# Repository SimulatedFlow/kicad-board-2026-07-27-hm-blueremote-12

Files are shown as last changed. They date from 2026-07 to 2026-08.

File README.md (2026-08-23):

# 2026-07-27-hm-blueremote-12

<!-- SF-STORE-BLOCK:BEGIN -->
## 🛒 Source-available — see before you buy

This repository contains the **full design files** of a commercial hardware board. It is **source-available, not open source**: read it, evaluate it, then buy a license to use it. See **LICENSE.md (source-available, purchase required)**.

**Get it / Buy:**
- **Order on eBay** (this board, bare PCB): https://www.ebay.de/itm/398223886097
- Product page (specs, photos, price): https://simulatedflow.teufel-engineering.com/platinen/2026-07-27-hm-blueremote-12/
- eBay store — all our boards and PCB art: https://www.ebay.de/usr/simula-9
- Merch shop (dev & gaming): https://simulatedflow.myspreadshop.de
- Merch shop (Synthetica / EDM): https://synthetica.myspreadshop.de
- Direct / invoice (Simulated Flow UG): simulatedflow@gmail.com

### 📬 **Free Board Documentation & Firmware Pack**

Schematics, BOMs and example-firmware docs for our STM32 carrier boards. Get it by joining the newsletter — plus a heads-up when something new ships. Double opt-in, unsubscribe in one click, no address sharing.

👉 **[Get the free pack](https://simulatedflow.teufel-engineering.com/newsletter/hardware/?q=gh)**

_© 2026 Simulated Flow UG. All rights reserved._
<!-- SF-STORE-BLOCK:END -->

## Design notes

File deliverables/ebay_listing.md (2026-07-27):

# HM-BlueRemote-12 - Leerplatine fuer STM32 Bluepill (unbestueckt/teilbestueckt, Bausatz-Basis)

Ein ultrakompakter 12-Tasten-Handsender für das Homematic-Ökosystem auf Basis eines STM32 Bluepill und CC1101-Funkmoduls.

## Highlights
- THT + SMD (Verkauf unbestueckt/teilbestueckt; schwer loetbare SMD optional fab-bestueckt)
- Passt direkt auf die STM32 'Bluepill' (2x 20-Pin-Buchsenleiste, 22,86 mm Reihenabstand)
- Schraubklemmen am Platinenrand - Kabel sauber nach aussen
- 4x M3-Befestigungsbohrungen fuer gaengige Gehaeuse
- 4-lagig (durchgehende GND- + Versorgungs-Plane, stoerarm/EMV-freundlich)

**Passendes Gehaeuse:** Hammond 1553B (Ergonomisches Handgehäuse, ca. 117x79x24mm)

## Einsatzzweck
Es fehlen fertige, anpassbare Homematic-Handsender (AskSinPP) mit hoher Tastenanzahl, die ohne Kabelsalat in ein Standard-Handgehäuse passen.

## Bestueckung (ca. 19 Bauteile laut Stueckliste)
- C1: 100nF (x1)
- C2: 10uF (x1)
- J1: 2xAAA 3V0 (x1)
- LED1: STATUS (x1)
- R1: 330 (x1)
- SW1: BTN1 (x1)
- SW2: BTN2 (x1)
- SW3: BTN3 (x1)
- SW4: BTN4 (x1)
- SW5: BTN5 (x1)
- SW6: BTN6 (x1)
- SW7: BTN7 (x1)
- SW8: BTN8 (x1)
- SW9: BTN9 (x1)
- SW10: BTN10 (x1)
- SW11: BTN11 (x1)
- SW12: BTN12 (x1)
- U1: STM32F103C8T6 (x1)
- U2: CC1101 (x1)

## Lieferumfang
- 1x unbestueckte Leiterplatte (Fertigung auf Bestellung via PCBWay)
- Schaltplan als PDF + Bestueckungsliste (BOM als CSV) zum Download

**Preis:** 19 EUR (unbestueckte Leerplatine, zzgl. Versand)

Fertigung auf Bestellung - Lieferzeit nach PCBWay-Produktion. Versand als versicherter Warenversand.

## Anbieter / Impressum (gewerblicher Verkauf)
Simulated Flow UG (haftungsbeschränkt)
Zeller Straße 37 A, 77833 Ottersweier, Deutschland
Vertreten durch den Geschäftsführer: Simulated Flow
Registergericht: Amtsgericht Mannheim, HRB 758925
USt-IdNr.: DE463825106
E-Mail: simulatedflow@gmail.com
Web: https://simulatedflow.teufel-engineering.com

Gewerblicher Verkauf durch die Simulated Flow UG — es gelten das gesetzliche Widerrufsrecht (14 Tage) und die gesetzliche Gewährleistung.

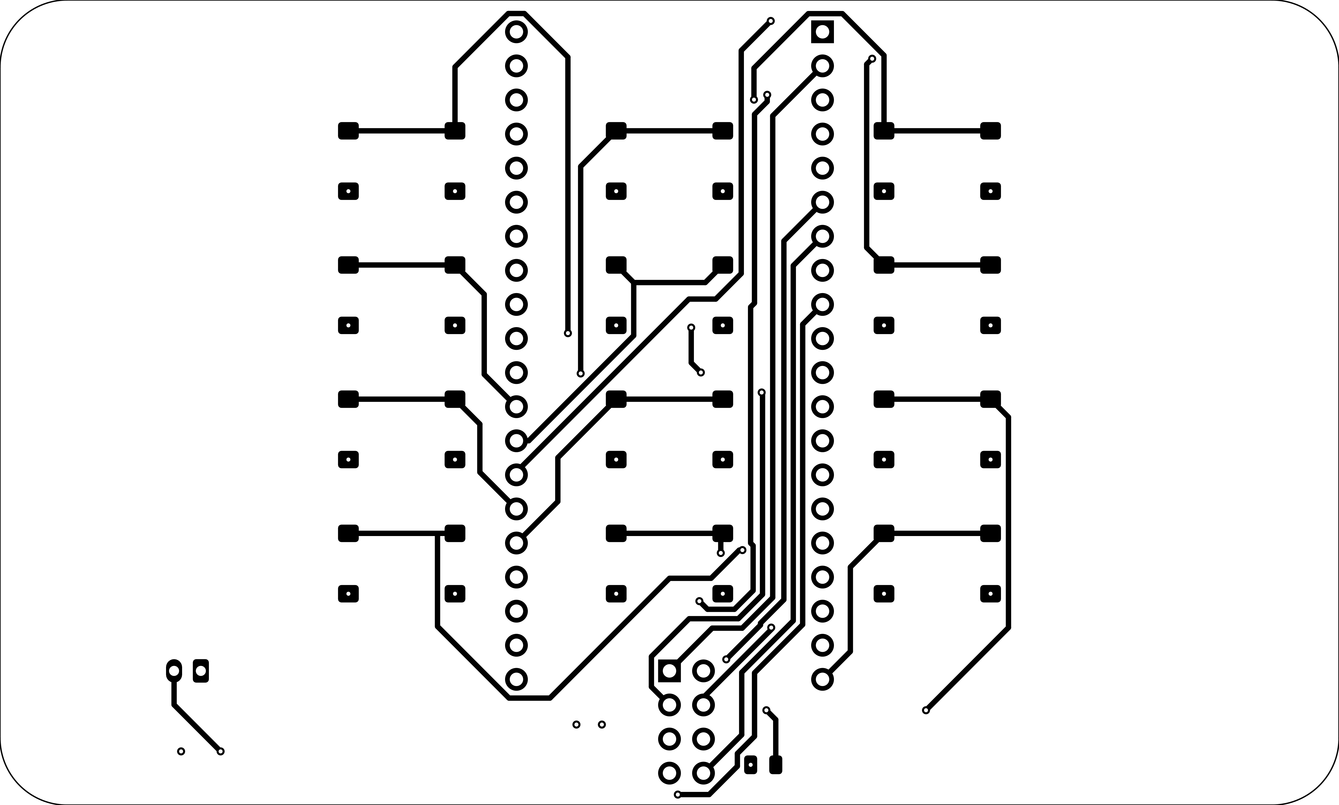
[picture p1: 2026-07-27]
HM-BlueRemote-12_2d_view.png

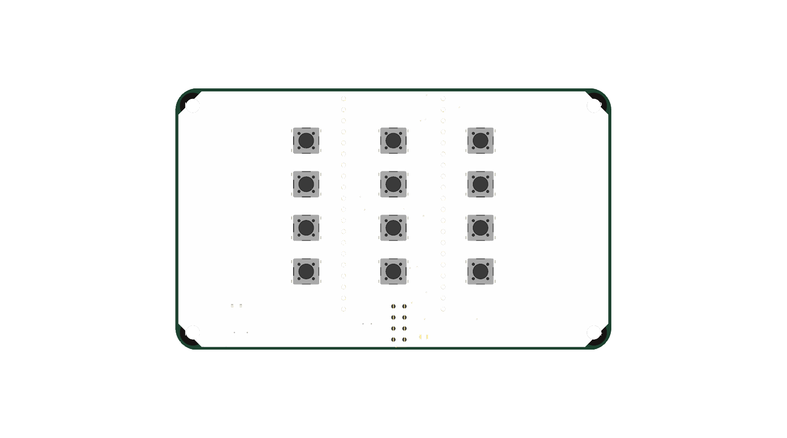
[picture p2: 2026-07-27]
deliverables/render_top.png

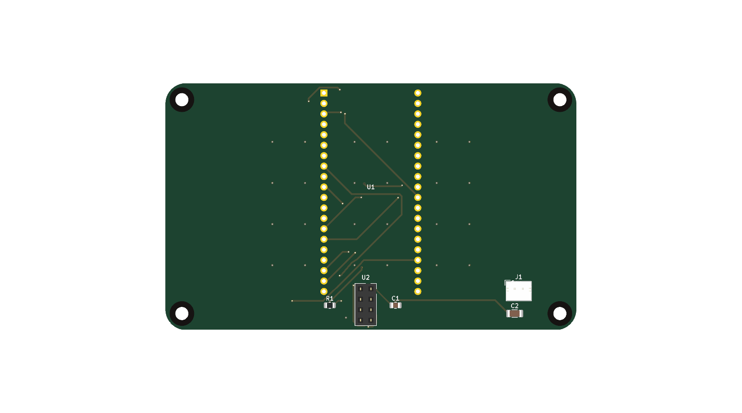
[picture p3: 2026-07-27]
deliverables/render_bottom.png

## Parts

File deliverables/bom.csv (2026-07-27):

Refs | Value | Footprint | Qty | DNP
C1 | 100nF | Capacitor_SMD:C_0805_2012Metric | 1
C2 | 10uF | Capacitor_SMD:C_1206_3216Metric | 1
J1 | 2xAAA 3V0 | Connector_JST:JST_PH_B2B-PH-K_1x02_P2.00mm_Vertical | 1
LED1 | STATUS | LED_SMD:LED_0805_2012Metric | 1
R1 | 330 | Resistor_SMD:R_0805_2012Metric | 1
SW1 | BTN1 | Button_Switch_SMD:SW_SPST_PTS645Sx43SMTR92 | 1
SW2 | BTN2 | Button_Switch_SMD:SW_SPST_PTS645Sx43SMTR92 | 1
SW3 | BTN3 | Button_Switch_SMD:SW_SPST_PTS645Sx43SMTR92 | 1
SW4 | BTN4 | Button_Switch_SMD:SW_SPST_PTS645Sx43SMTR92 | 1
SW5 | BTN5 | Button_Switch_SMD:SW_SPST_PTS645Sx43SMTR92 | 1
SW6 | BTN6 | Button_Switch_SMD:SW_SPST_PTS645Sx43SMTR92 | 1
SW7 | BTN7 | Button_Switch_SMD:SW_SPST_PTS645Sx43SMTR92 | 1
SW8 | BTN8 | Button_Switch_SMD:SW_SPST_PTS645Sx43SMTR92 | 1
SW9 | BTN9 | Button_Switch_SMD:SW_SPST_PTS645Sx43SMTR92 | 1
SW10 | BTN10 | Button_Switch_SMD:SW_SPST_PTS645Sx43SMTR92 | 1
SW11 | BTN11 | Button_Switch_SMD:SW_SPST_PTS645Sx43SMTR92 | 1
SW12 | BTN12 | Button_Switch_SMD:SW_SPST_PTS645Sx43SMTR92 | 1
U1 | STM32F103C8T6 | HM-BlueRemote-12:Bluepill_Socket_2x20 | 1
U2 | CC1101 | Connector_PinSocket_2.54mm:PinSocket_2x04_P2.54mm_Vertical | 1

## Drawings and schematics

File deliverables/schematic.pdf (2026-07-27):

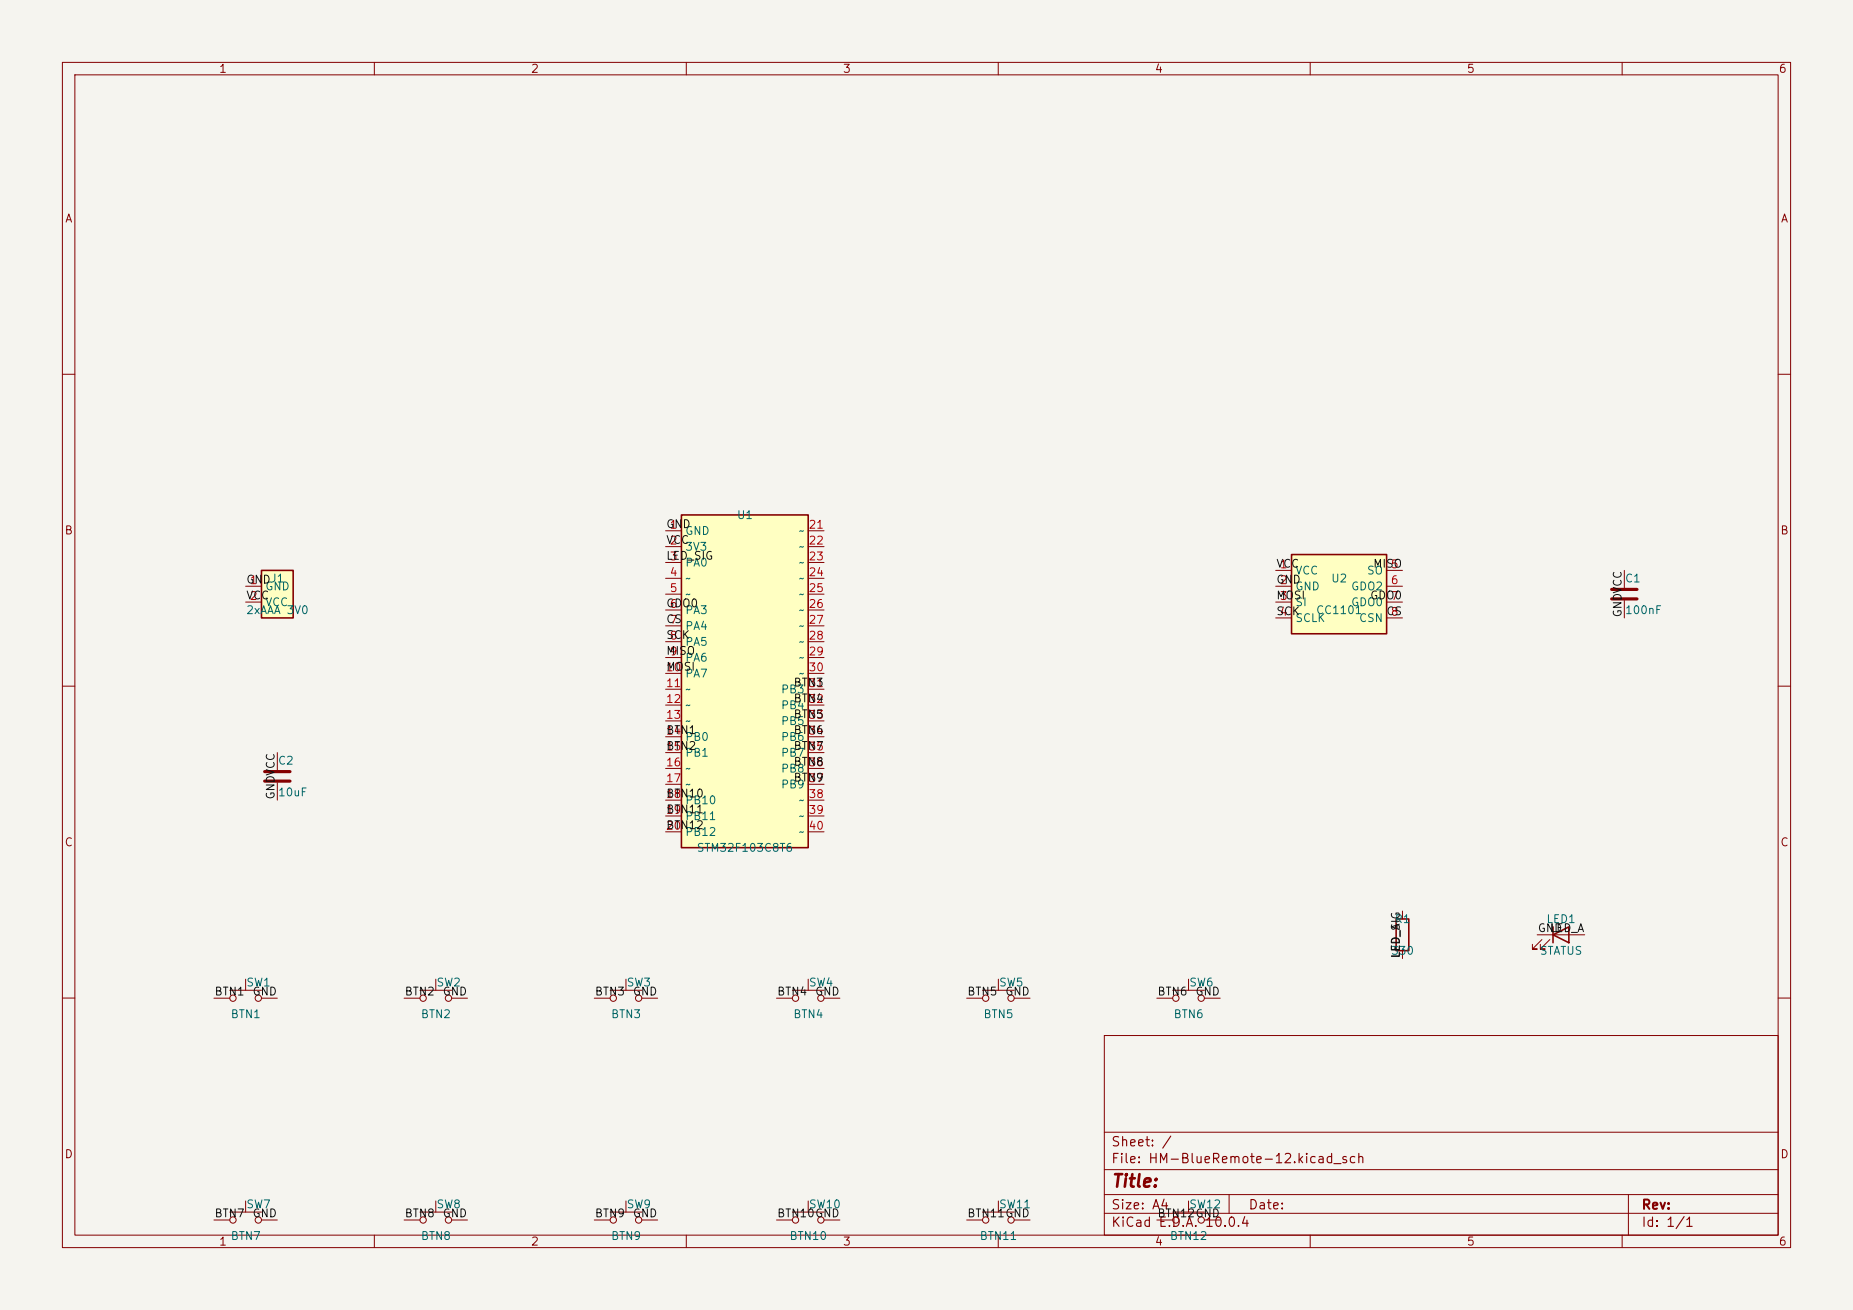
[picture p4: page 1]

Size: A4 | Rev:
SW12 BTN12 KiCad E.D.A. 10.0.4 | Id: 1/1

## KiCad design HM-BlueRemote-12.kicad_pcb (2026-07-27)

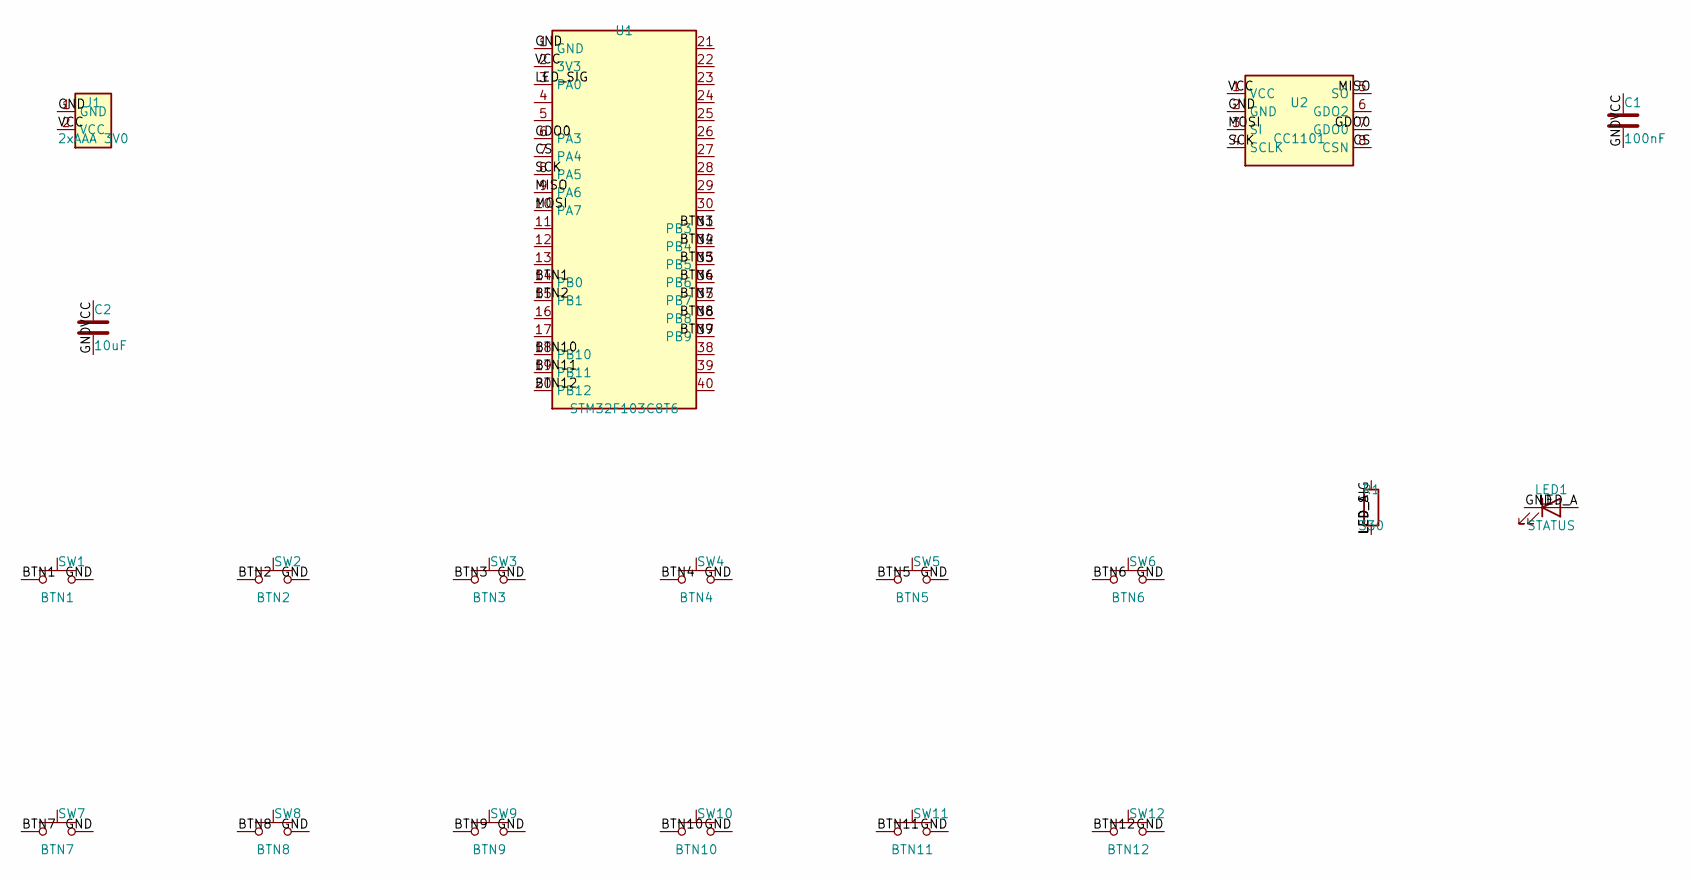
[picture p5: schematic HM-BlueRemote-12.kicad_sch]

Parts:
C1: 100nF; C_0805_2012Metric
C2: 10uF; C_1206_3216Metric
J1: 2xAAA 3V0; JST_PH_B2B-PH-K_1x02_P2.00mm_Vertical
LED1: STATUS; LED_0805_2012Metric
R1: 330; R_0805_2012Metric
SW1: BTN1; SW_SPST_PTS645Sx43SMTR92
SW2: BTN2; SW_SPST_PTS645Sx43SMTR92
SW3: BTN3; SW_SPST_PTS645Sx43SMTR92
SW4: BTN4; SW_SPST_PTS645Sx43SMTR92
SW5: BTN5; SW_SPST_PTS645Sx43SMTR92
SW6: BTN6; SW_SPST_PTS645Sx43SMTR92
SW7: BTN7; SW_SPST_PTS645Sx43SMTR92
SW8: BTN8; SW_SPST_PTS645Sx43SMTR92
SW9: BTN9; SW_SPST_PTS645Sx43SMTR92
SW10: BTN10; SW_SPST_PTS645Sx43SMTR92
SW11: BTN11; SW_SPST_PTS645Sx43SMTR92
SW12: BTN12; SW_SPST_PTS645Sx43SMTR92
U1: STM32F103C8T6; Bluepill_Socket_2x20
U2: CC1101; PinSocket_2x04_P2.54mm_Vertical

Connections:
BTN1: SW1.1, U1.14 (PB0)
BTN2: SW2.1, U1.15 (PB1)
BTN3: SW3.1, U1.31 (PB3)
BTN4: SW4.1, U1.32 (PB4)
BTN5: SW5.1, U1.33 (PB5)
BTN6: SW6.1, U1.34 (PB6)
BTN7: SW7.1, U1.35 (PB7)
BTN8: SW8.1, U1.36 (PB8)
BTN9: SW9.1, U1.37 (PB9)
BTN10: SW10.1, U1.18 (PB10)
BTN11: SW11.1, U1.19 (PB11)
BTN12: SW12.1, U1.20 (PB12)
CS: U1.7 (PA4), U2.8 (CSN)
GDO0: U1.6 (PA3), U2.7 (GDO0)
GND: C1.2, C2.2, J1.1 (GND), LED1.1 (K), SW1.2, SW2.2, SW3.2, SW4.2, SW5.2, SW6.2, SW7.2, SW8.2, SW9.2, SW10.2, SW11.2, SW12.2, U1.1 (GND), U2.2 (GND)
LED_A: LED1.2 (A), R1.2
LED_SIG: R1.1, U1.3 (PA0)
MISO: U1.9 (PA6), U2.5 (SO)
MOSI: U1.10 (PA7), U2.3 (SI)
SCK: U1.8 (PA5), U2.4 (SCLK)
VCC: C1.1, C2.1, J1.2 (VCC), U1.2 (3V3), U2.1 (VCC)

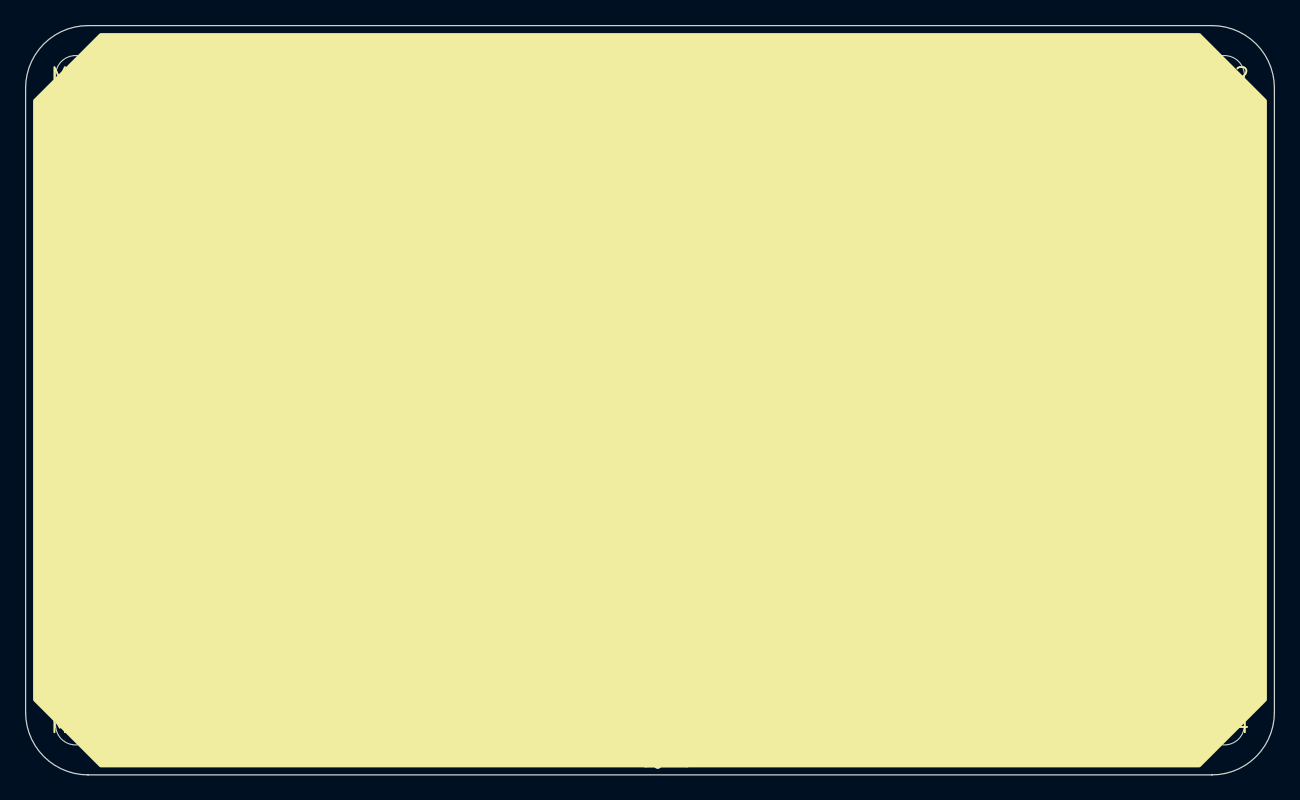
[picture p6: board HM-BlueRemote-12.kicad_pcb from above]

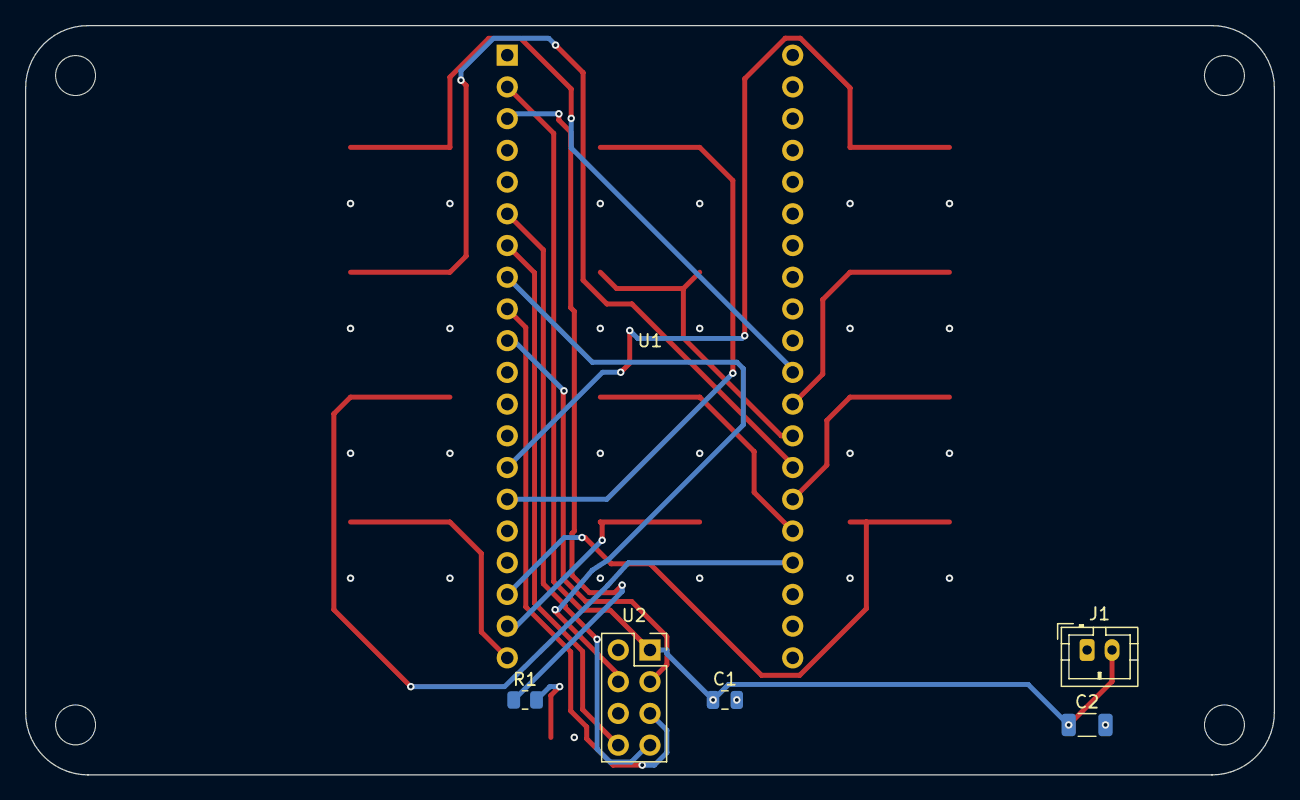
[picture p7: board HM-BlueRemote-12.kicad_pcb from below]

Board: 4 copper layers, 100.0 x 60.0 mm, 23 parts (6 on the bottom side), 21 nets.

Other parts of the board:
MH1, MH2, MH3, MH4: MountingHole_3.2mm

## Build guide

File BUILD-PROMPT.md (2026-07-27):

```json
{
  "board_name": "HM-BlueRemote-12",
  "one_liner": "Ein ultrakompakter 12-Tasten-Handsender für das Homematic-Ökosystem auf Basis eines STM32 Bluepill und CC1101-Funkmoduls.",
  "market_gap": "Es fehlen fertige, anpassbare Homematic-Handsender (AskSinPP) mit hoher Tastenanzahl, die ohne Kabelsalat in ein Standard-Handgehäuse passen.",
  "confidence": "high",
  "price_eur": 19,
  "target_enclosure": "Hammond 1553B (Ergonomisches Handgehäuse, ca. 117x79x24mm)",
  "injection_notes": "keine"
}
```

Hallo Silvan! Hier ist das perfekt durchdachte Design für deinen Homematic-Handsender. Die Platine ist für das extrem beliebte Open-Source-Ökosystem **AskSinPP** optimiert und passt perfekt in das standardmäßig erhältliche, ergonomische **Hammond 1553B** Gehäuse. 

Um die Komplexitätsgrenzen für ein stabiles Autorouting streng einzuhalten, verwenden wir die internen Pull-ups des STM32, was uns erlaubt, alle 12 Tasten direkt ohne externe Pull-up-Widerstände anzubinden. Damit bleiben wir bei sensationell schlanken **19 Bauteilen** für die gesamte Platine! Die Taster sitzen auf der Vorderseite, während die Bluepill und das CC1101-Modul platzsparend auf der Rückseite platziert sind.

---

## BUILD-PROMPT

Baue ein 4-Lagen-PCB-Projekt in KiCad für das Board `HM-BlueRemote-12`. Folge exakt diesen Spezifikationen:

### 1. HARTE DFM-VORGABEN & GEOMETRIE
- **Platinengröße:** 100.0 mm × 60.0 mm, rechteckig mit abgerundeten Ecken (Radius R = 5.0 mm).
- **Montagebohrungen:** 4× M3-Befestigungslöcher (Durchmesser 3.2 mm, Pad-Durchmesser 6.0 mm, unkontaktiert), exakt platziert bei den Koordinaten:
  - (4.0, 4.0) mm
  - (96.0, 4.0) mm
  - (4.0, 56.0) mm
  - (96.0, 56.0) mm
- **Keepouts:** Kreisförmiger Keepout-Bereich (Radius 5.0 mm) um alle vier Befestigungslöcher für Leiterbahnen und Kupferflächen.
- **Leiterbahnen & Abstände (4-Lagen):**
  - **Lagen-Stackup:** F.Cu (Signal), In1.Cu (GND-Plane), In2.Cu (3.3V-Plane), B.Cu (Signal).
  - Netzklasse `Default`: Clearance = 0.3 mm, Track Width = 0.4 mm.
  - Netzklasse `Power` (VCC, GND): Clearance = 0.3 mm, Track Width = 0.8 mm.
  - Vias: Bohrung 0.3 mm, Pad 0.6 mm.

### 2. STÜCKLISTE (19 BAUTEILE GESAMT)
- **U1:** STM32F103C8T6 Bluepill Sockel. Bestehend aus 2× einreihigen Buchsenleisten `PinSocket_1x20_P2.54mm_Vertical` (Reihenabstand 0.9″ / 22.86 mm). Platziert auf der **Rückseite (B.Cu)**:
  - Reihe 1 (Pins 1-20): X = 38.57 mm, Y = 25.0 mm
  - Reihe 2 (Pins 21-40): X = 61.43 mm, Y = 25.0 mm
- **U2:** CC1101 868MHz Funkmodul (Standard-Modul, grün). Footprint: 2x4-polige Buchsenleiste `PinSocket_2x04_P2.54mm_Vertical_DualRow` (RM 2.54). Platziert auf der **Rückseite (B.Cu)** bei X = 50.0 mm, Y = 50.0 mm.
- **SW1 bis SW12:** 12× SMD-Taster (6x6 mm, z. B. `SW_SPST_PTS645` oder ähnlich handlötbar). Platziert auf der **Vorderseite (F.Cu)** im ergonomischen 3×4-Grid:
  - Spalte 1: X = 30.0 mm | Spalte 2: X = 50.0 mm | Spalte 3: X = 70.0 mm
  - Reihe 1: Y = 12.0 mm (SW1, SW2, SW3)
  - Reihe 2: Y = 22.0 mm (SW4, SW5, SW6)
  - Reihe 3: Y = 32.0 mm (SW7, SW8, SW9)
  - Reihe 4: Y = 42.0 mm (SW10, SW11, SW12)
- **J1:** Batterie-Eingang für 2xAAA (3.0V). Footprint: JST-PH 2-Pin `Connector_JST_JST-PH-2-Pin` (RM 2.00 mm). Platziert auf der **Rückseite (B.Cu)** bei X = 15.0 mm, Y = 50.0 mm. Pin 1 = GND, Pin 2 = VCC.
- **LED1:** Sende-/Status-LED. Footprint: SMD-LED `LED_0805_2012Metric` (oder 1206). Platziert auf der **Vorderseite (F.Cu)** bei X = 50.0 mm, Y = 52.0 mm.
- **R1:** LED-Vorwiderstand 330 Ohm. Footprint: SMD-Widerstand `R_0805_2012Metric`. Platziert auf der **Rückseite (B.Cu)**.
- **C1:** Entkopplungskondensator 100 nF. Footprint: SMD-Kondensator `C_0805_2012Metric`. Platziert auf der **Rückseite (B.Cu)** sehr nah an den Stromversorgungspins von U2.
- **C2:** Bulk-Kondensator 10 µF. Footprint: SMD-Kondensator `C_1206_3216Metric`. Platziert auf der **Rückseite (B.Cu)** nah bei J1.

### 3. NETZE & VERBINDUNGEN
- **Power-Netze:**
  - `VCC` (3.3V/Batteriestrom): J1 Pin 2 -> U1 Pin 3.3V -> U2 Pin 1 -> C1 Pin 1 -> C2 Pin 1.
  - `GND`: J1 Pin 1 -> U1 GND -> U2 Pin 2 -> C1 Pin 2 -> C2 Pin 2 -> LED1 Kathode -> Pin 2 aller Taster (SW1-SW12).
- **CC1101 Funk-Schnittstelle:**
  - SPI1 MOSI: U2 Pin 3 (SI) -> Net `MOSI` -> U1 Pin PA7 (Pin 10)
  - SPI1 MISO: U2 Pin 5 (SO) -> Net `MISO` -> U1 Pin PA6 (Pin 9)
  - SPI1 SCK: U2 Pin 4 (SCLK) -> Net `SCK` -> U1 Pin PA5 (Pin 8)
  - SPI1 CS: U2 Pin 8 (CSN) -> Net `CS` -> U1 Pin PA4 (Pin 7)
  - Interrupt GDO0: U2 Pin 7 (GDO0) -> Net `GDO0` -> U1 Pin PA3 (Pin 6)
- **Status-Anzeige:**
  - Net `LED_SIG`: U1 Pin PA0 (Pin 3) -> R1 Pin 1 -> R1 Pin 2 -> LED1 Anode.
- **Taster-GPIOs (Direktanbindung):**
  - Pin 1 aller Taster geht direkt auf einen separaten GPIO der Bluepill (GND-Schaltung mit internem Pull-Up):
    - SW1 -> Net `BTN1` -> U1 Pin PB0 (Pin 14)
    - SW2 -> Net `BTN2` -> U1 Pin PB1 (Pin 15)
    - SW3 -> Net `BTN3` -> U1 Pin PB3 (Pin 31)
    - SW4 -> Net `BTN4` -> U1 Pin PB4 (Pin 32)
    - SW5 -> Net `BTN5` -> U1 Pin PB5 (Pin 33)
    - SW6 -> Net `BTN6` -> U1 Pin PB6 (Pin 34)
    - SW7 -> Net `BTN7` -> U1 Pin PB7 (Pin 35)
    - SW8 -> Net `BTN8` -> U1 Pin PB8 (Pin 36)
    - SW9 -> Net `BTN9` -> U1 Pin PB9 (Pin 37)
    - SW10 -> Net `BTN10` -> U1 Pin PB10 (Pin 18)
    - SW11 -> Net `BTN11` -> U1 Pin PB11 (Pin 19)
    - SW12 -> Net `BTN12` -> U1 Pin PB12 (Pin 20)

### 4. WORKFLOW & INTEGRATION
1. Erzeuge das KiCad-Projekt `HM-BlueRemote-12` im Workspace.
2. Generiere den Schaltplan mit allen angegebenen Netzen und Bauteilen.
3. Erstelle das PCB-Layout, setze die Boardgrenzen (100x60mm, R=5) und platziere die Bauteile streng nach Koordinatenvorgabe. 
4. Definiere die zwei durchgehenden Innenlagen (In1.Cu = GND, In2.Cu = VCC) und verbinde die Netze.
5. Führe den Freerouting-Autorouter aus.
6. Führe den DRC-Lauf durch, um die Integrität sicherzustellen.
7. Exportiere die Gerber- und Bohrdateien vollständig nach `./gerbers`.

Führe alle Schritte autonom aus und gib am Ende eine ehrliche Zusammenfassung der Ergebnisse zurück.

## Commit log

2026-07-27 auto-backup 2026-07-27 17:26:34
    [HM-BlueRemote-12.dsn, HM-BlueRemote-12.kicad_pcb, HM-BlueRemote-12.kicad_sch]
2026-07-27 auto-backup 2026-07-27 18:26:35
    [HM-BlueRemote-12-B_Courtyard.gbr, HM-BlueRemote-12-B_Cu.gbl, HM-BlueRemote-12-B_Fab.gbr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]
